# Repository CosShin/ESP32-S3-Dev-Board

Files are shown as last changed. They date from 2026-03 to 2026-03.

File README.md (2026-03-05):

# ESP32-S3 Custom Development Board

## Overview
This project is a custom ESP32-S3 development board designed for IoT and AI applications.

## Features
- ESP32-S3-WROOM module
- USB-C power input
- AMS1117 5V to 3.3V regulator
- I2S Microphone interface
- TFT LCD connector
- Reset and Boot buttons

## PCB Specs
- 2-layer PCB
- FR4 1.6mm
- 1oz copper
- Designed in KiCad 8

## Images

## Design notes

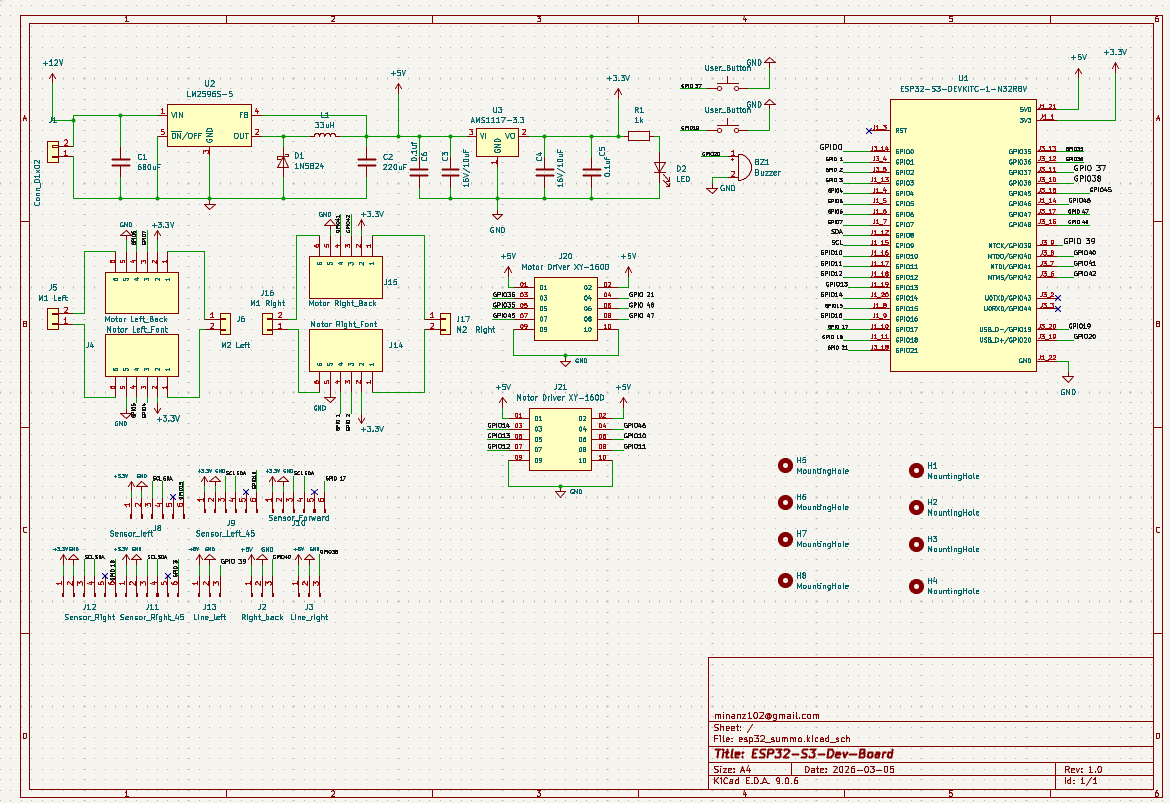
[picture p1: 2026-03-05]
image/schematic.png

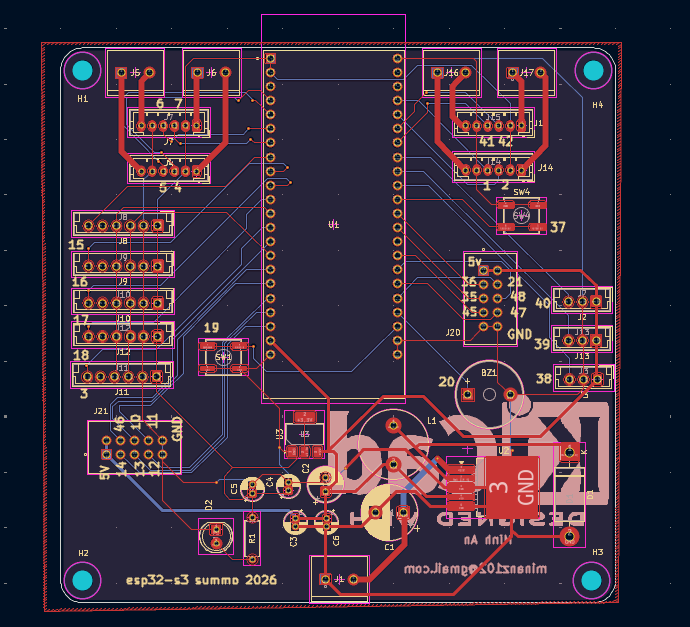
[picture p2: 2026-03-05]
image/pcb.png

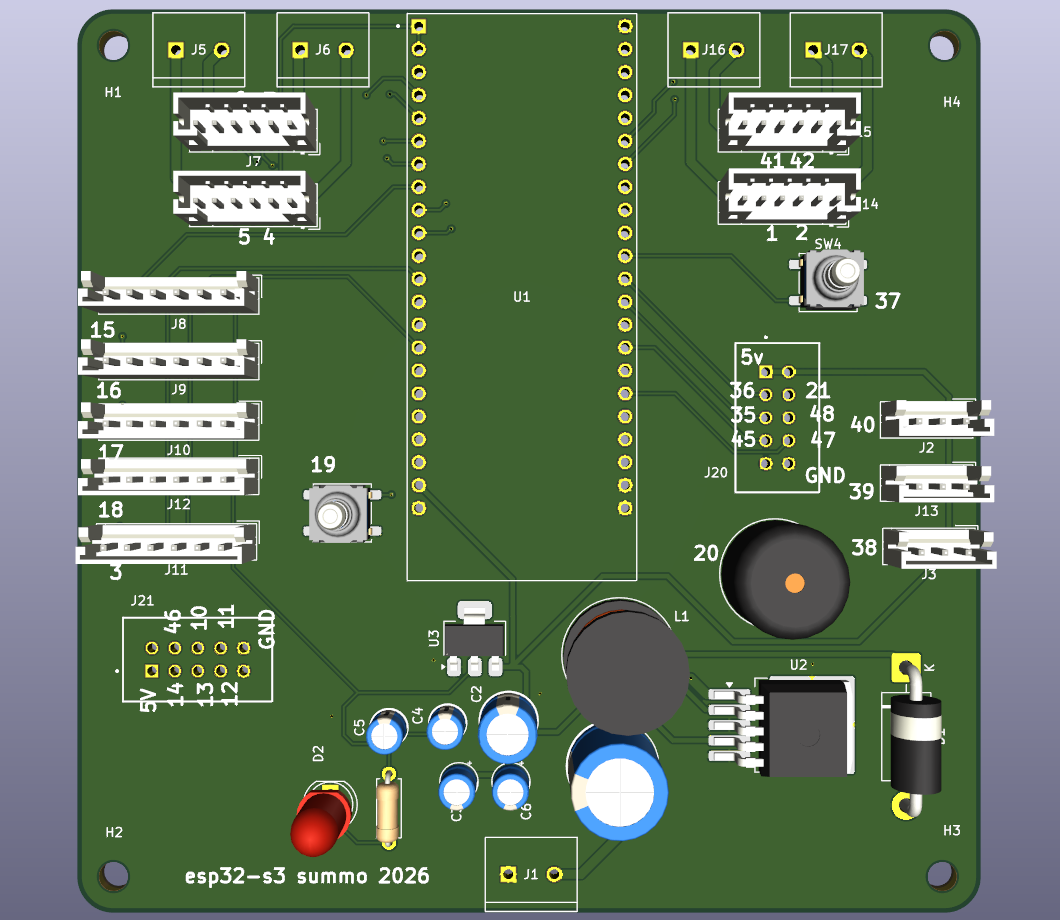
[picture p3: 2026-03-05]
image/3d.png

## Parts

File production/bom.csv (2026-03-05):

Designator | Footprint | Quantity | Value | LCSC Part #
BZ1 | Buzzer_12x9.5RM7.6 | 1 | Buzzer
C1 | CP_Radial_D10.0mm_P5.00mm | 1 | 680uF
C2 | CP_Radial_D6.3mm_P2.50mm | 1 | 220uF
C3, C4 | CP_Radial_D4.0mm_P1.50mm | 2 | 16V/10uF
C5, C6 | CP_Radial_D4.0mm_P1.50mm | 2 | 0.1uf
D1 | D_DO-201AD_P15.24mm_Horizontal | 1 | 1N5824
D2 | LED_D5.0mm | 1 | LED
J1 | TE_282837-2 | 1 | Conn_01x02
J10 | JST_EH_B6B-EH-A_1x06_P2.50mm_Vertical | 1 | Sensor_Forward
J11 | JST_EH_B6B-EH-A_1x06_P2.50mm_Vertical | 1 | Sensor_Right_45
J12 | JST_EH_B6B-EH-A_1x06_P2.50mm_Vertical | 1 | Sensor_Right
J13 | JST_EH_B3B-EH-A_1x03_P2.50mm_Vertical | 1 | Line_left
J14 | JST_PH_B6B-PH-K_1x06_P2.00mm_Vertical | 1 | Motor Right_Font
J15 | JST_PH_B6B-PH-K_1x06_P2.00mm_Vertical | 1 | Motor Right_Back
J16 | TE_282837-2 | 1 | M1 Right
J17 | TE_282837-2 | 1 | M2 Right
J2 | JST_EH_B3B-EH-A_1x03_P2.50mm_Vertical | 1 | Right_back
J20, J21 | SAMTEC_ZSS-105-01-S-D-480 | 2 | Motor Driver XY-160D
J3 | JST_EH_B3B-EH-A_1x03_P2.50mm_Vertical | 1 | Line_right
J4 | JST_PH_B6B-PH-K_1x06_P2.00mm_Vertical | 1 | Motor Left_Font
J5 | TE_282837-2 | 1 | M1 Left
J6 | TE_282837-2 | 1 | M2 Left
J7 | JST_PH_B6B-PH-K_1x06_P2.00mm_Vertical | 1 | Motor Left_Back
J8 | JST_EH_B6B-EH-A_1x06_P2.50mm_Vertical | 1 | Sensor_left
J9 | JST_EH_B6B-EH-A_1x06_P2.50mm_Vertical | 1 | Sensor_Left_45
L1 | L_Radial_D12.5mm_P7.00mm_Fastron_09HCP | 1 | 33uH
R1 | R_Axial_DIN0207_L6.3mm_D2.5mm_P7.62mm_Horizontal | 1 | 1k
SW1, SW4 | SW_Push_1P1T_NO_CK_KSC9xxJ | 2 | User_Button
U1 | XCVR_ESP32-S3-DEVKITC-1-N32R8V | 1 | ESP32-S3-DEVKITC-1-N32R8V
U2 | TO-263-5_TabPin3 | 1 | LM2596S-5
U3 | SOT-223-3_TabPin2 | 1 | AMS1117-3.3

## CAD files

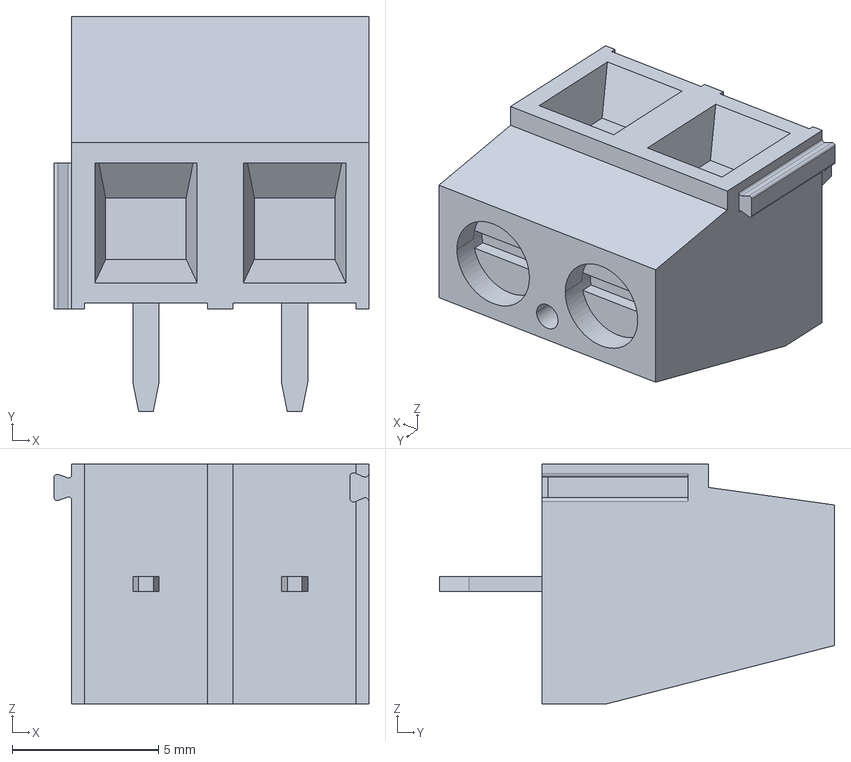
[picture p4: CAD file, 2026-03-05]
282837-2.step
10.8 x 13.5 x 8.20 mm

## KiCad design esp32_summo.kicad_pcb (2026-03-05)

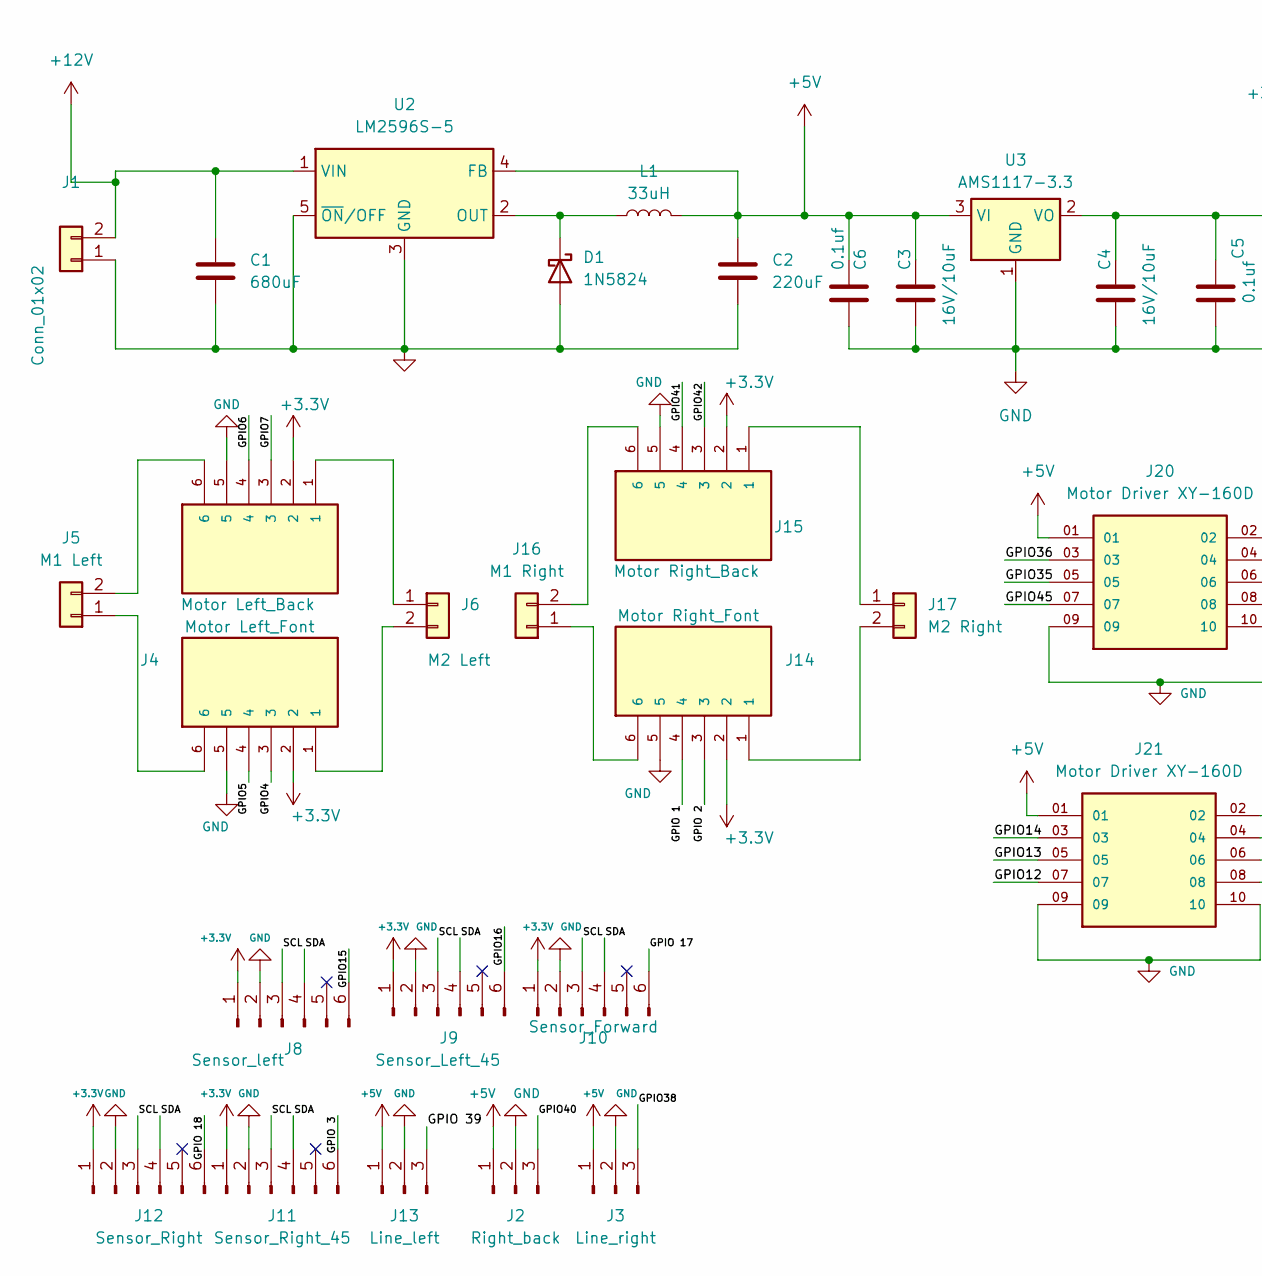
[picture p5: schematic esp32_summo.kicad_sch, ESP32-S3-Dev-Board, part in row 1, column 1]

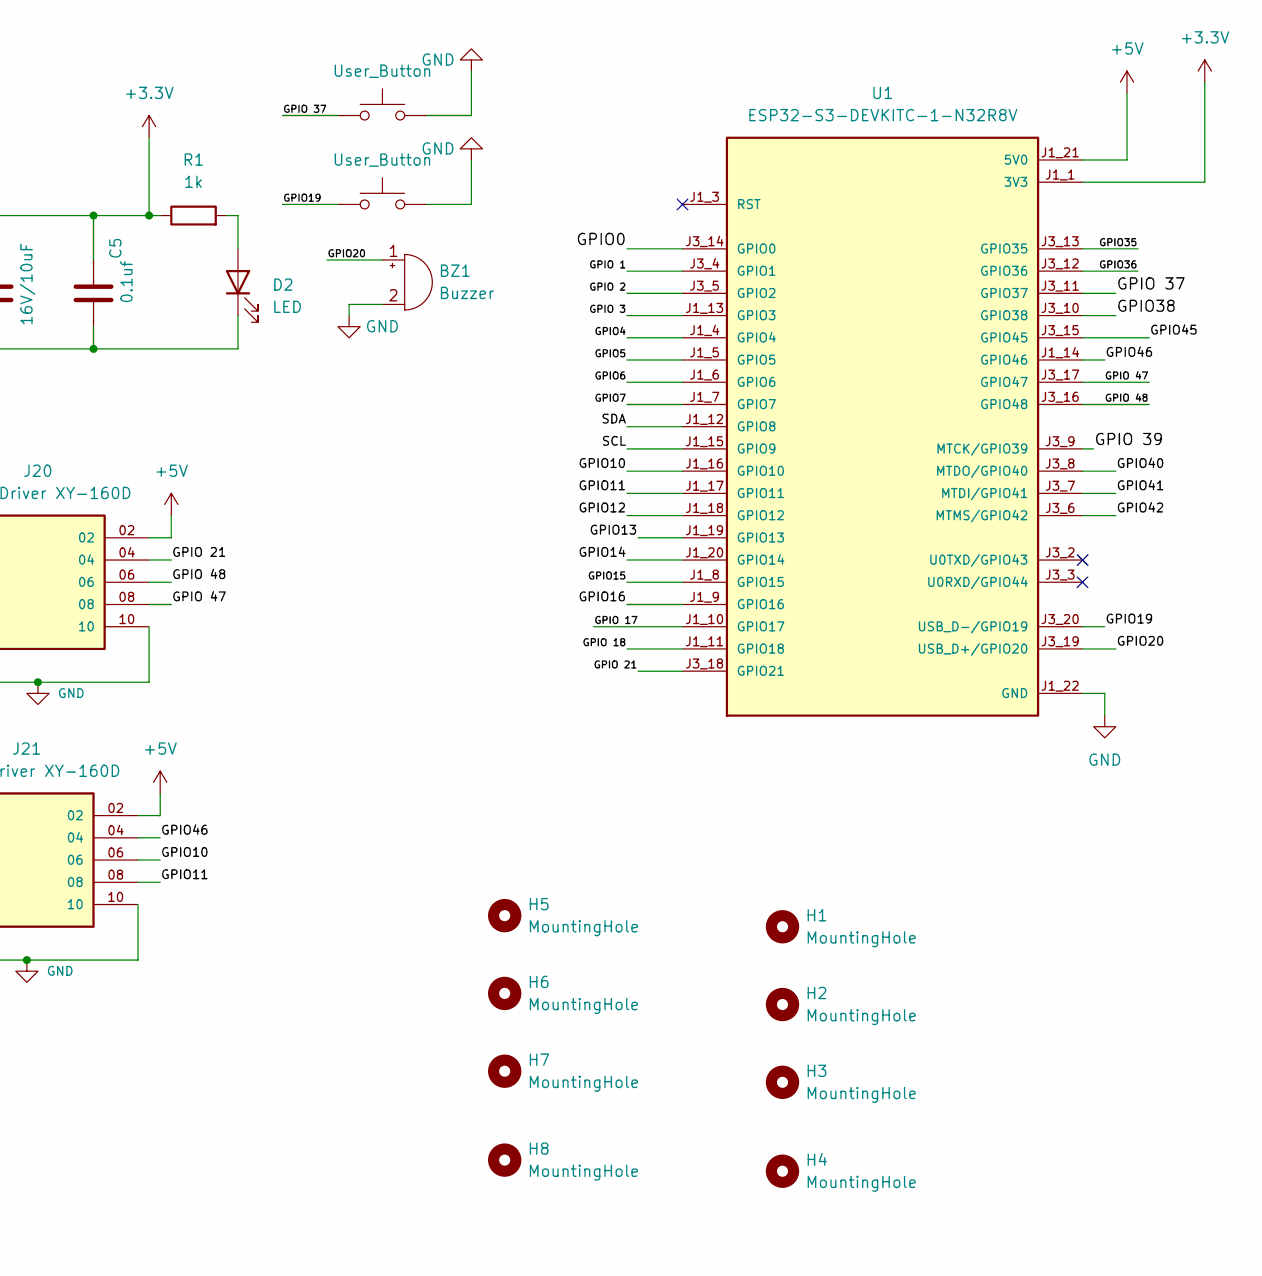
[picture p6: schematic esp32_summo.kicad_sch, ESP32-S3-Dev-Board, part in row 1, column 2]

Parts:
BZ1: Buzzer; Buzzer_12x9.5RM7.6
C1: 680uF; CP_Radial_D10.0mm_P5.00mm
C2: 220uF; CP_Radial_D6.3mm_P2.50mm
C3, C4: 16V/10uF; CP_Radial_D4.0mm_P1.50mm
C5, C6: 0.1uf; CP_Radial_D4.0mm_P1.50mm
D1: 1N5824; D_DO-201AD_P15.24mm_Horizontal
D2: LED; LED_D5.0mm
H1, H2, H3, H4, H5, H6, H7, H8: MountingHole; MountingHole_3.2mm_M3
J1: Conn_01x02; TE_282837-2
J2: Right_back; JST_EH_B3B-EH-A_1x03_P2.50mm_Vertical
J3: Line_right; JST_EH_B3B-EH-A_1x03_P2.50mm_Vertical
J4: Motor Left_Font; JST_PH_B6B-PH-K_1x06_P2.00mm_Vertical; PARTREV N/A
J5: M1 Left; TE_282837-2
J6: M2 Left; TE_282837-2
J7: Motor Left_Back; JST_PH_B6B-PH-K_1x06_P2.00mm_Vertical; PARTREV N/A
J8: Sensor_left; JST_EH_B6B-EH-A_1x06_P2.50mm_Vertical
J9: Sensor_Left_45; JST_EH_B6B-EH-A_1x06_P2.50mm_Vertical
J10: Sensor_Forward; JST_EH_B6B-EH-A_1x06_P2.50mm_Vertical
J11: Sensor_Right_45; JST_EH_B6B-EH-A_1x06_P2.50mm_Vertical
J12: Sensor_Right; JST_EH_B6B-EH-A_1x06_P2.50mm_Vertical
J13: Line_left; JST_EH_B3B-EH-A_1x03_P2.50mm_Vertical
J14: Motor Right_Font; JST_PH_B6B-PH-K_1x06_P2.00mm_Vertical; PARTREV N/A
J15: Motor Right_Back; JST_PH_B6B-PH-K_1x06_P2.00mm_Vertical; PARTREV N/A
J16: M1 Right; TE_282837-2
J17: M2 Right; TE_282837-2
J20, J21: Motor Driver XY-160D; SAMTEC_ZSS-105-01-S-D-480; PARTREV T
L1: 33uH; L_Radial_D12.5mm_P7.00mm_Fastron_09HCP
R1: 1k; R_Axial_DIN0207_L6.3mm_D2.5mm_P7.62mm_Horizontal
SW1, SW4: User_Button; SW_Push_1P1T_NO_CK_KSC9xxJ
U1: ESP32-S3-DEVKITC-1-N32R8V; XCVR_ESP32-S3-DEVKITC-1-N32R8V; PARTREV 1.1
U2: LM2596S-5; TO-263-5_TabPin3
U3: AMS1117-3.3; SOT-223-3_TabPin2

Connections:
+3.3V: C4.1, C5.1, J4.2, J7.2, J8.1, J9.1, J10.1, J11.1, J12.1, J14.2, J15.2, R1.1, U1.J1_1 (3V3), U1.J1_2 (3V3), U3.2 (VO)
+5V: C2.1, C3.1, C6.1, J2.1, J3.1, J13.1, J20.01, J20.02, J21.01, J21.02, L1.2, U1.J1_21 (5V0), U2.4 (FB), U3.3 (VI)
+12V: C1.1, J1.2, U2.1 (VIN)
/GPIO0: U1.J3_14 (GPIO0)
/GPIO4: J4.3, U1.J1_4 (GPIO4)
/GPIO5: J4.4, U1.J1_5 (GPIO5)
/GPIO6: J7.4, U1.J1_6 (GPIO6)
/GPIO7: J7.3, U1.J1_7 (GPIO7)
/GPIO10: J21.06, U1.J1_16 (GPIO10)
/GPIO11: J21.08, U1.J1_17 (GPIO11)
/GPIO12: J21.07, U1.J1_18 (GPIO12)
/GPIO13: J21.05, U1.J1_19 (GPIO13)
/GPIO14: J21.03, U1.J1_20 (GPIO14)
/GPIO15: J8.6, U1.J1_8 (GPIO15)
/GPIO16: J9.6, U1.J1_9 (GPIO16)
/GPIO19: SW1.1, U1.J3_20 (USB_D-/GPIO19)
/GPIO20: BZ1.1 (+), U1.J3_19 (USB_D+/GPIO20)
/GPIO35: J20.05, U1.J3_13 (GPIO35)
/GPIO36: J20.03, U1.J3_12 (GPIO36)
/GPIO38: J3.3, U1.J3_10 (GPIO38)
/GPIO40: J2.3, U1.J3_8 (MTDO/GPIO40)
/GPIO41: J15.4, U1.J3_7 (MTDI/GPIO41)
/GPIO42: J15.3, U1.J3_6 (MTMS/GPIO42)
/GPIO45: J20.07, U1.J3_15 (GPIO45)
/GPIO46: J21.04, U1.J1_14 (GPIO46)
/GPIO 1: J14.4, U1.J3_4 (GPIO1)
/GPIO 2: J14.3, U1.J3_5 (GPIO2)
/GPIO 3: J11.6, U1.J1_13 (GPIO3)
/GPIO 17: J10.6, U1.J1_10 (GPIO17)
/GPIO 18: J12.6, U1.J1_11 (GPIO18)
/GPIO 21: J20.04, U1.J3_18 (GPIO21)
/GPIO 37: SW4.1, U1.J3_11 (GPIO37)
/GPIO 39: J13.3, U1.J3_9 (MTCK/GPIO39)
/GPIO 47: J20.08, U1.J3_17 (GPIO47)
/GPIO 48: J20.06, U1.J3_16 (GPIO48)
/SCL: J8.3, J9.3, J10.3, J11.3, J12.3, U1.J1_15 (GPIO9)
/SDA: J8.4, J9.4, J10.4, J11.4, J12.4, U1.J1_12 (GPIO8)
GND: BZ1.2 (-), C1.2, C2.2, C3.2, C4.2, C5.2, C6.2, D1.2 (A), D2.1 (K), J1.1, J2.2, J3.2, J4.5, J7.5, J8.2, J9.2, J10.2, J11.2, J12.2, J13.2, J14.5, J15.5, J20.09, J20.10, J21.09, J21.10, SW1.2, SW4.2, U1.J1_22 (GND), U1.J3_1 (GND), U1.J3_21 (GND), U1.J3_22 (GND), U2.3 (GND), U2.5 (~ON/OFF), U3.1 (GND)
unnamed: D1.1 (K), L1.1, U2.2 (OUT)
unnamed: D2.2 (A), R1.2
unnamed: J4.6, J5.1
unnamed: J5.2, J7.6
unnamed: J6.1, J7.1
unnamed: J4.1, J6.2
unnamed: J14.6, J16.1
unnamed: J15.6, J16.2
unnamed: J15.1, J17.1
unnamed: J14.1, J17.2

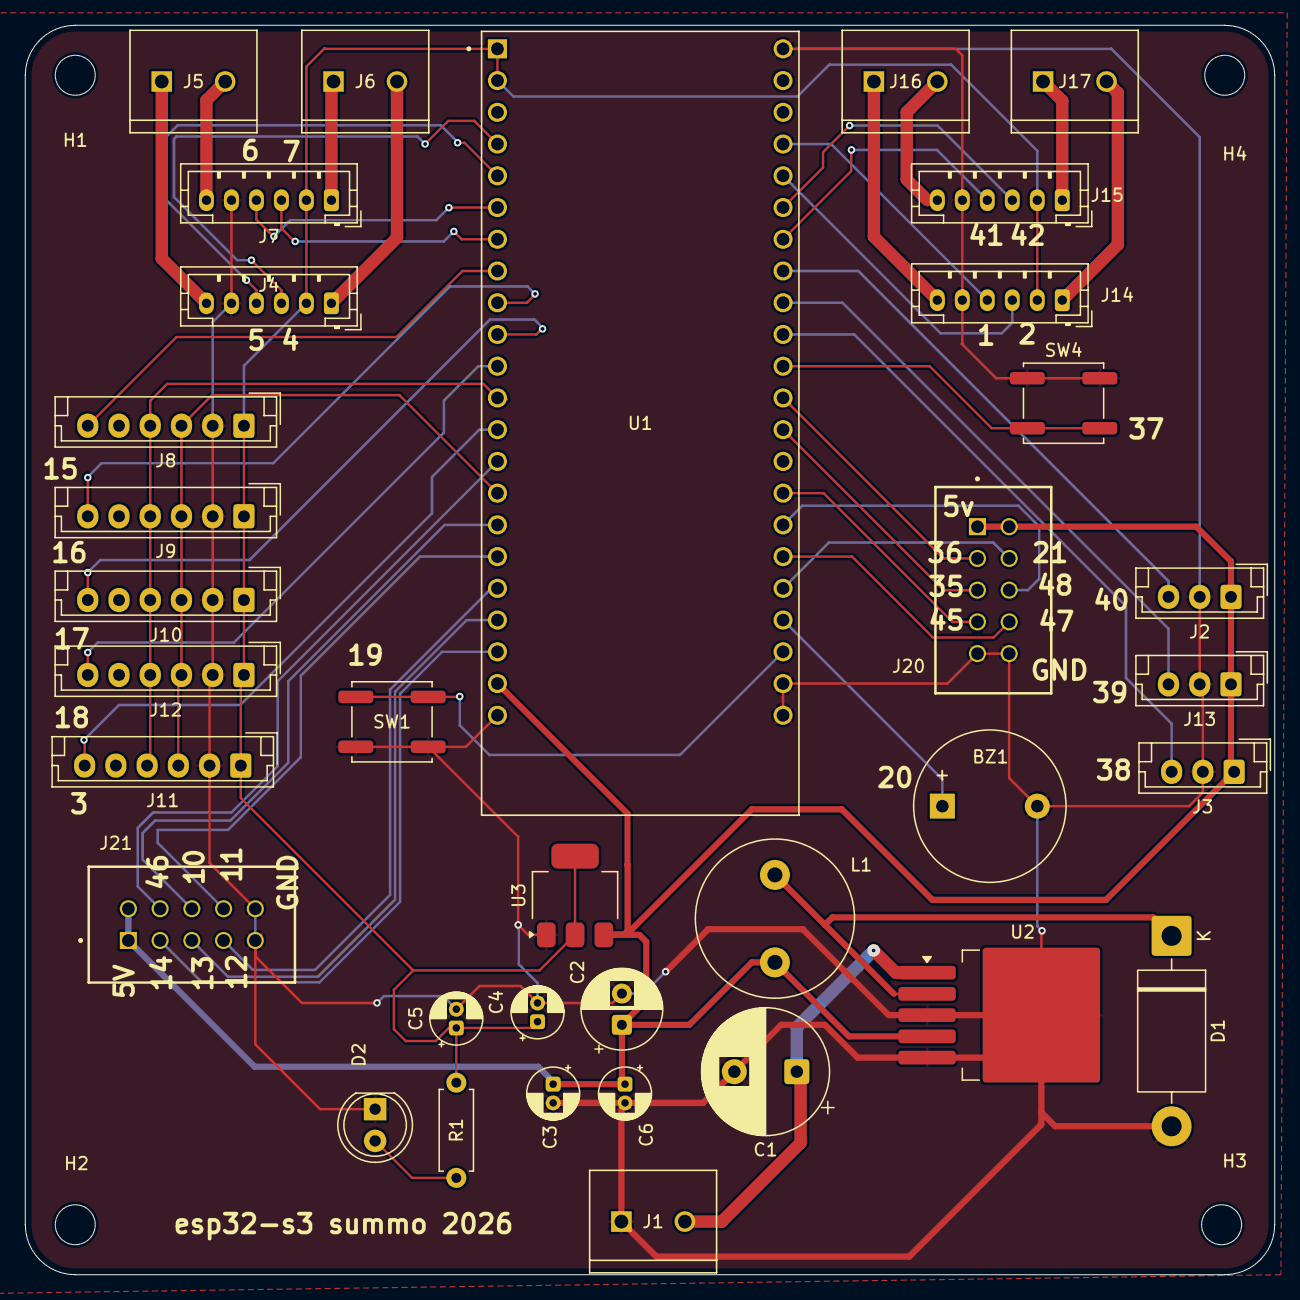
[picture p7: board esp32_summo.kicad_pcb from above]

Board: 2 copper layers, 100.0 x 100.0 mm, 39 parts (0 on the bottom side), 47 nets.
